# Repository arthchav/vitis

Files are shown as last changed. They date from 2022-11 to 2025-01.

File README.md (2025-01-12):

<p align="center">

  Vitis-Logo
</p>
Pour consulter les fonctionnalités et la réalisation du robot, veuillez consulter le document "Vitis - Rapport final de projet.pdf" dans les fichiers ci-dessus !

---------------------------------------------------

*"Vitis is a robot made for vineyards to help remove weeds under the vines. It runs on electricity, has four wheels, and can be controlled by a smartphone in manual or autonomous mode. It can move through different types of land, avoid small obstacles, and use a camera to recognize objects. The robot is easy to control and works well, but it will be improved to track vine rows better and add tools for removing weeds more effectively."*

# Last video : 

https://youtu.be/JAuiAB0MdsA

<p align="center">
  
</p>

### Playlist : 

https://youtube.com/playlist?list=PLRQ-Vj44Z8fejHV95dyqV7iqJ9uM6nV9p

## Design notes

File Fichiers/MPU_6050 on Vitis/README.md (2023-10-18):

# MPU-6050 on Vitis

<p align="center">

  Vitis-Logo
</p>

In our 4th year Robotics course, we had to use an inertial unit in a project. We naturally chose Vitis and the aim of the course is to display a cube representing Vitis moving in 3 dimensions. 

We used Arduino and Processing to display the cubes in 3D. 
There are 3 different codes, the first only with an accelerometer, the second only with a gyrometer and the last with both. 

<p align="center">

  Vitis-Logo
</p>

Finally, there's a bonus Arduino code for a remote control that controls the robot with the remote control's Roll and Pitch angles (Android smartphone only). 

<p align="center">

  Vitis-Logo
</p>

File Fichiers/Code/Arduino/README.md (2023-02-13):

## Code Arduino 

Dans section se trouve toutes les explications concernant les codes Arduino. pour l'instant il n'y a que 2 programmes qui seront combinés par la suite. 

Dans le futur ce dossier aura : 

- Un seul code qui combine le mode manuel et le mode automatique. 
- Des class, .h et .cpp qui rendent le code plus lisible et l'allège un peu.

<p align="center">
  
</p>

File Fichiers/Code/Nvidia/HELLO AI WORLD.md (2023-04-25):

# Running the Docker Container:

```
$ git clone --recursive https://github.com/dusty-nv/jetson-inference
$ cd jetson-inference
$ docker/run.sh
```
# Building the project from the Source:

### Cloning the Repository

```
$ sudo apt-get update
$ sudo apt-get install git cmake
```

```
$ git clone https://github.com/dusty-nv/jetson-inference
$ cd jetson-inference
$ git submodule update --init
```
### Python Packages

```
$ sudo apt-get install libpython3-dev python3-numpy
```

### Configuring with CMake

```
$ cd jetson-inference    # omit if working directory is already jetson-inference/ from above
$ mkdir build
$ cd build
$ cmake ../
```

### Installing PyTorch

```
$ cd jetson-inference/build
$ ./install-pytorch.sh
```

### Compiling the Project

```
$ cd jetson-inference/build          # omit if working directory is already build/ from above
$ make
$ sudo make install
$ sudo ldconfig
```

# Classifying Images with ImageNet

### Using the ImageNet Program on Jetson

```
$ cd jetson-inference/build/aarch64/bin
```

### Example

```
$ ./imagenet.py images/orange_0.jpg images/test/output_0.jpg  # (default network is googlenet)

$ ./imagenet.py images/strawberry_0.jpg images/test/output_1.jpg
```

Pour une vidéo:

```
$ wget https://nvidia.box.com/shared/static/tlswont1jnyu3ix2tbf7utaekpzcx4rc.mkv -O jellyfish.mkv

$ ./imagenet.py --network=resnet-18 jellyfish.mkv images/test/jellyfish_resnet18.mkv
```

# Coding Your Own Image Recognition Program (Python)

### Setting up the Project

```
# run these commands outside of container
$ cd ~/
$ mkdir my-recognition-python
$ cd my-recognition-python
$ touch my-recognition.py
$ chmod +x my-recognition.py
$ wget https://github.com/dusty-nv/jetson-inference/raw/master/data/images/black_bear.jpg 
$ wget https://github.com/dusty-nv/jetson-inference/raw/master/data/images/brown_bear.jpg
$ wget https://github.com/dusty-nv/jetson-inference/raw/master/data/images/polar_bear.jpg 
```
```
$ jetson-inference/docker/run.sh --volume ~/my-recognition-python:/my-recognition-python   # mounted inside the container to /my-recognition-python 
```

### Source Code

```
vim my-recognition.py
```
```
#!/usr/bin/python3

import jetson.inference
import jetson.utils

import argparse

# parse the command line
parser = argparse.ArgumentParser()
parser.add_argument("filename", type=str, help="filename of the image to process")
parser.add_argument("--network", type=str, default="googlenet", help="model to use, can be:  googlenet, resnet-18, ect.")
args = parser.parse_args()

# load an image (into shared CPU/GPU memory)
img = jetson.utils.loadImage(args.filename)

# load the recognition network
net = jetson.inference.imageNet(args.network)

# classify the image
class_idx, confidence = net.Classify(img)

# find the object description
class_desc = net.GetClassDesc(class_idx)

# print out the result
print("image is recognized as '{:s}' (class #{:d}) with {:f}% confidence".format(class_desc, class_idx, confidence * 100))
```

### Running Example

```
$ ./my-recognition.py polar_bear.jpg
image is recognized as 'ice bear, polar bear, Ursus Maritimus, Thalarctos maritimus' (class #296) with 99.999878% confidence
```

# Running the Live Camera Recognition Demo

Faire le Tuto 'Stream Vidéo'

```
imagenet --bitrate=1000000 --output-codec=h264 /dev/video0 rtp://172.20.10.2:9306
```

```
detectnet --bitrate=1000000 --output-codec=h264 /dev/video0 rtp://172.20.10.2:9306
```

Lancer la vidéo sur VLC et régalez-vous!

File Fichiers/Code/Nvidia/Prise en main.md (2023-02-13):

# Prise en main de la carte jetson nano:

<p align="center">
  
</p>

<p align="center">
  
</p>

Connexion à la carte jetson nano:
```shell
 ssh vitis@192.168.55.1
 ```

 # Déplacer le stockage de la mémoire nvidia vers la carte SD:

On check les partitions pour voir le nom de la carte avec la commande:

```shell
lsblk
```
La carte SD ce nomme "mmcblk1p1".

On veut maintenant la formater au format ext4 en tapant la commande:

```shell
sudo mkfs.ext4 /dev/mmcblk1p1
```
On crée ensuite un point de montage:

```shell
sudo mkdir -p /usr/Documents
```

Puis on monte la partition:

```shell
sudo mount -t auto /dev/mmclk1p1 /usr/Documents
```

On vérifie que la partition est bien montée avec:
```shell
lsblk -f
```

On copie /home vers le nouvel emplacement:

```shell
sudo rsync -avx /home/ /usr/Documents
```
On monte la nouvelle partition:
```shell
sudo mount /dev/mmcblk1p1
```

On récupère le UUID de la nouvelle partition et on modifie le fstab:

```shell
sudo blkid
sudo vim /etc/fstab
UUID=03d60d39-967e-473e-b710-2687941e1d0a /home ext4 defaults 0 2
```

Finalement on redémarre la carte et /home est désormais sur la carte SD
```shell
sudo shutdown -r now
```

# Utiliser les images docker fournies par Nvidia:

Installer le package nvidia-container, attention à bien être connecté en wifi avec la carte(voir annexe):
```shell
sudo apt install nvidia-container
```
On modifie le fichier /etc/docker/daemon.json en ajoutant:
```shell
"data-root":"/mnt/sd_card"
```

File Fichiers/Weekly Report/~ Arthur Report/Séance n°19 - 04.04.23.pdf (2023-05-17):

Arthur | Rapport de séance n°19 | Projet Vitis
| | 04/04/23

Objectifs de la séance :

- Fixer les drivers aux planches
- Fixer les planches au châssis
- Trouver une solution pour partager l’alimentation autre que des dominos.

Réalisations :

- Tout d’abord pré perçage et fixation des drivers aux planches avec vis et écrou de 3mm.

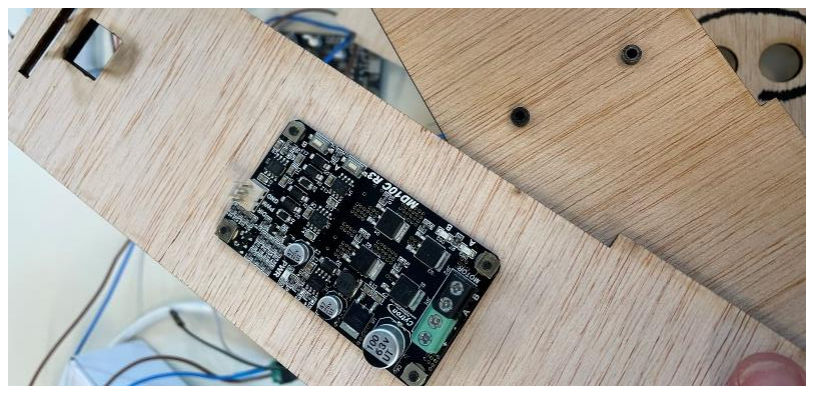
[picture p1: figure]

- On vient ensuite assembler les planches entre elles à l’aide d’équerres que je place en diagonale opposé par rapport au châssis car je n’ai que 2 équerres.

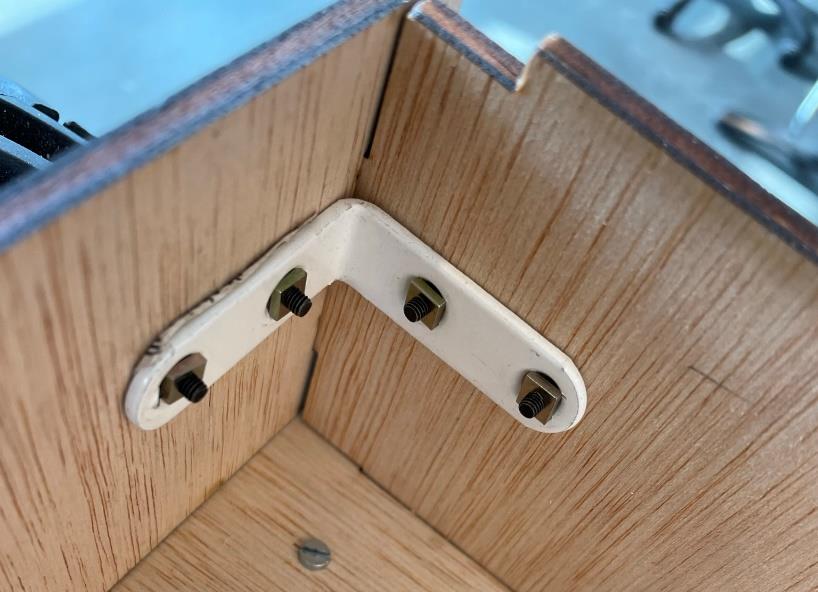
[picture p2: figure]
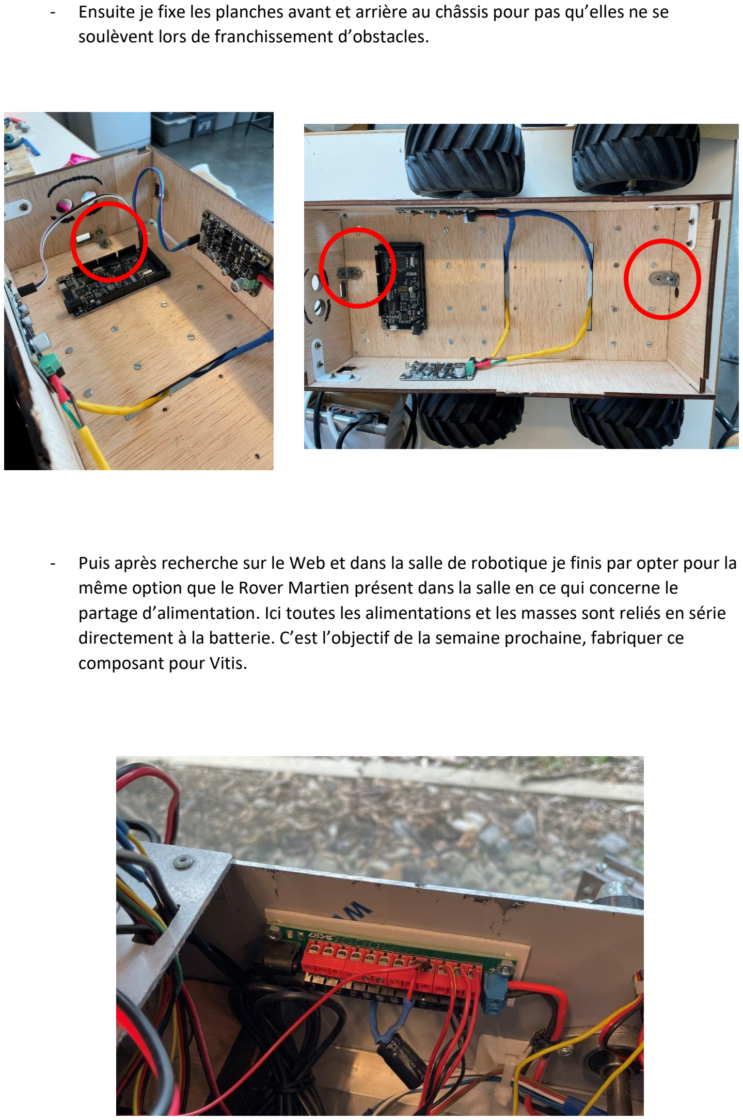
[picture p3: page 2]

- Ensuite je fixe les planches avant et arrière au châssis pour pas qu’elles ne se soulèvent lors de franchissement d’obstacles.
- Puis après recherche sur le Web et dans la salle de robotique je finis par opter pour la même option que le Rover Martien présent dans la salle en ce qui concerne le partage d’alimentation. Ici toutes les alimentations et les masses sont reliés en série directement à la batterie. C’est l’objectif de la semaine prochaine, fabriquer ce composant pour Vitis.

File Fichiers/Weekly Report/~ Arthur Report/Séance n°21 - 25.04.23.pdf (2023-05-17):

Arthur | Rapport de séance n°21 | Projet Vitis
| | 25/04/23

Objectifs de la séance :

- Fabriquer un composant pour partager la masse de la carte Arduino Mega.
- Changement du bois pour le plexiglas pour les 4 planches fixées au châssis.

Réalisations :

- Je commence par réaliser un composant où je peux connecter plus de10 masses ensemble puisque la carte Arduino ne possède pas assez de ports pour tout nos capteurs.

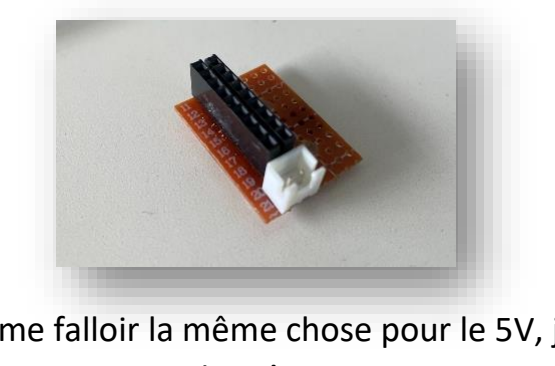
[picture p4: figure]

Après réflexion il va me falloir la même chose pour le 5V, je décide donc de recommencer pour avoir tout sur la même carte.

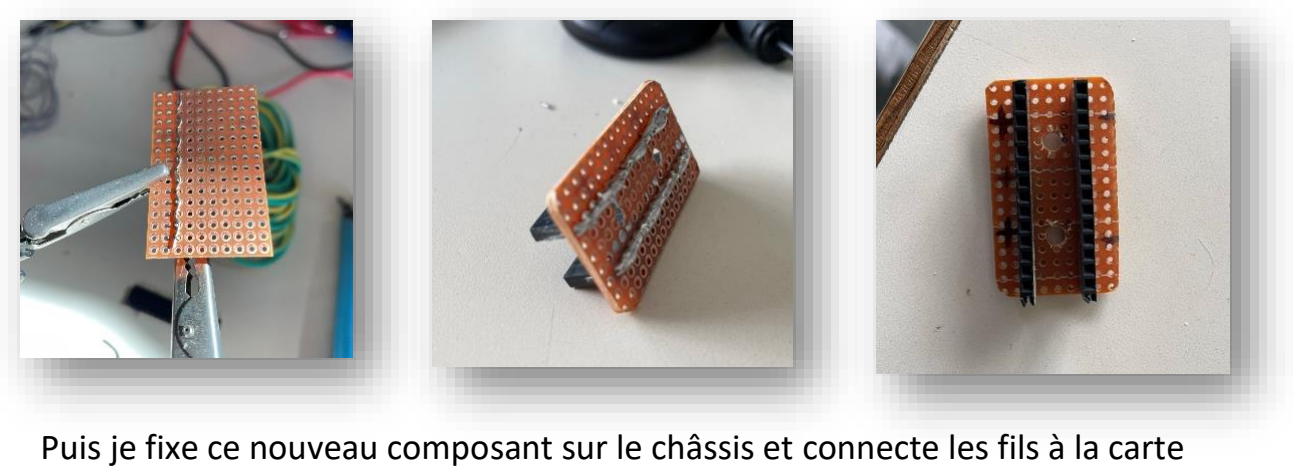
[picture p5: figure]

Puis je fixe ce nouveau composant sur le châssis et connecte les fils à la carte Arduino.

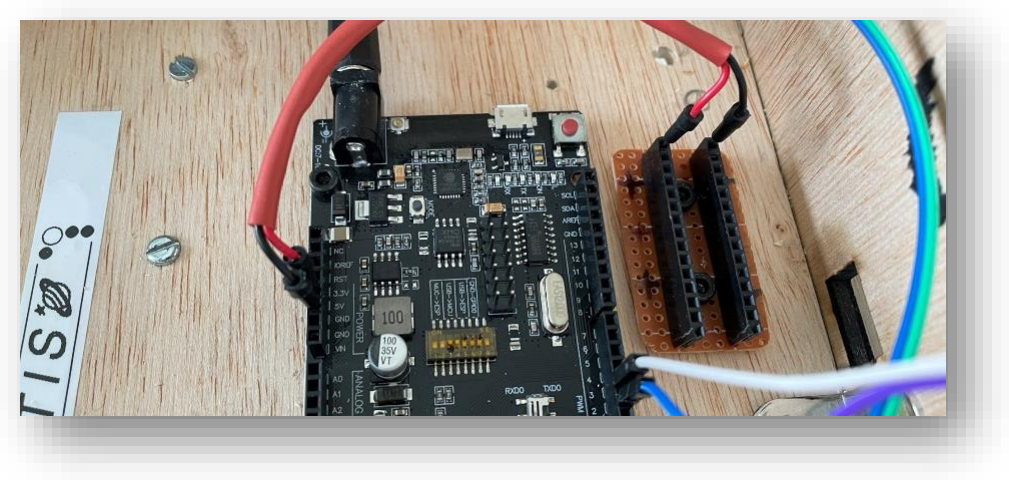
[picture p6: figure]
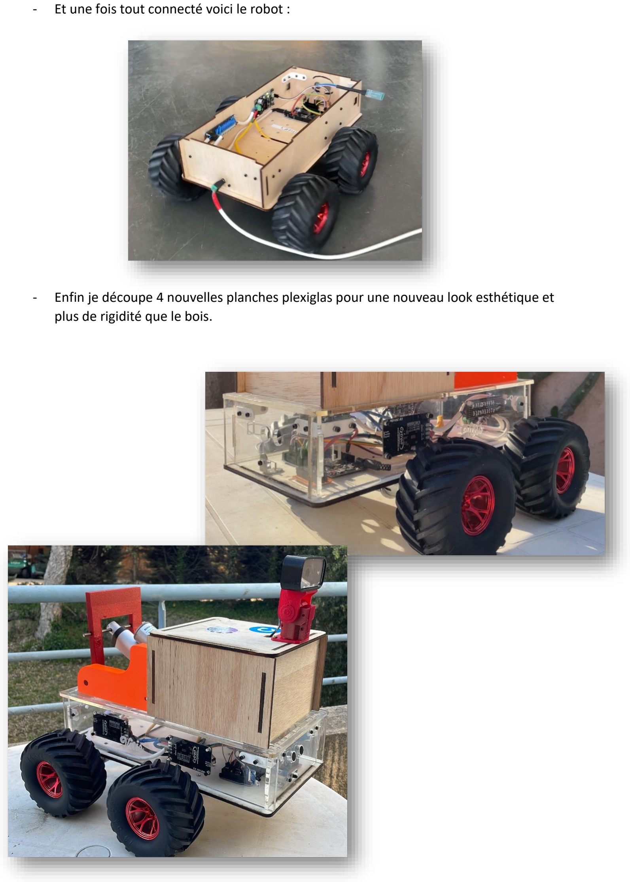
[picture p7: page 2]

- Et une fois tout connecté voici le robot :
- Enfin je découpe 4 nouvelles planches plexiglas pour une nouveau look esthétique et plus de rigidité que le bois.

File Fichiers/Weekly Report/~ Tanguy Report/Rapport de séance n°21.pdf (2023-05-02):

Rapport de Séance 02/05/23

Objectifs de séance:
-Carte Nvidia reconnaissance d’image -Programme Arduino servo-moteurs
I-Carte Nvidia Reconnaissance d’image

https://github.com/arthchav/vitis/tree/main/WorkSpace/Code%Vitis/Nvidia

II-Programme Arduino

Pour finir la partie sur la caméra, j’ai écris un code Arduino afin de permettre une rotation des servo-moteurs périodique. Cela permettra d’avoir une grande amplitude de capture d’image.

Code pour 1 servo-moteur:

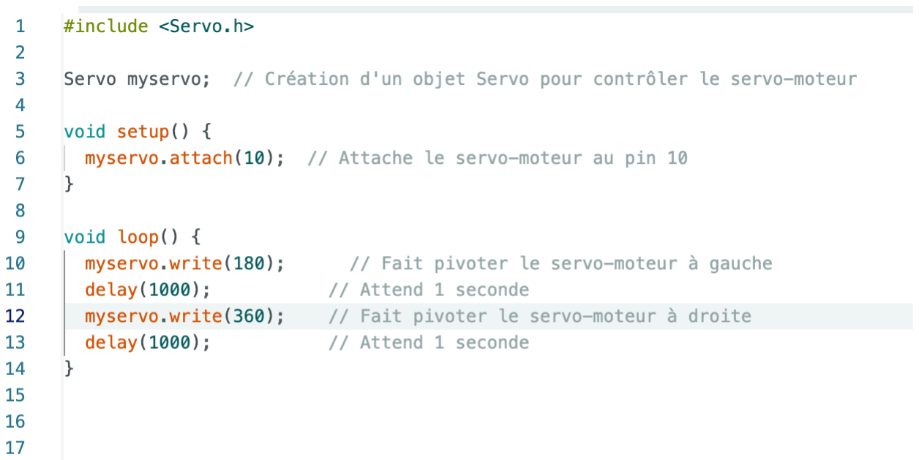
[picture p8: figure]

Code pour 2 servo-moteurs:

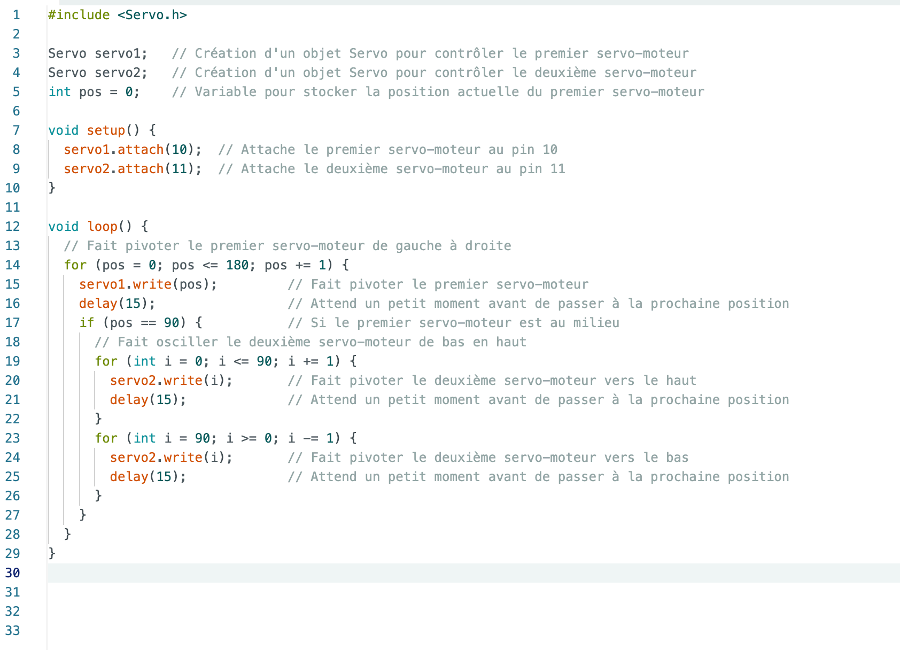
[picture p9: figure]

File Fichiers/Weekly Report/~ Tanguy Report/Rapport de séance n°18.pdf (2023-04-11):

Rapport de Séance 04/04/23

Objectifs de séance:
-Installation caméra
-Carte Nvidia reconnaissance d’image
I-Installation Caméra

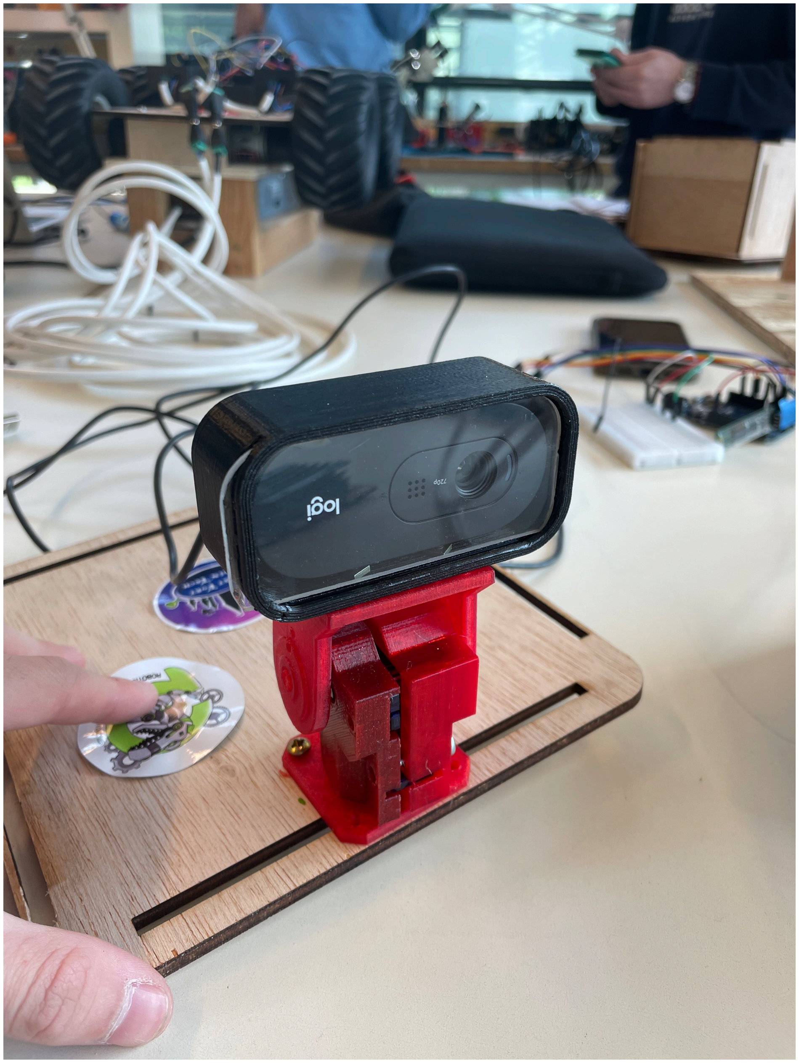
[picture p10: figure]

J’ai commencé par découper la vitre en plexi avec la découpeuse laser. Ensuite j’ai fixé à l’aide de vis la caméra au support tournant. Maintenant on a un bloc complet qui permet de bouger la caméra dans à peu près tout les sens qu’on veut. Ce support sera relié à la carte Arduino et la caméra sera relié à la carte Nvidia afin de pouvoir faire de la reconnaissance d’image.

II-Carte Nvidia Reconnaissance d’image

Voir tuto Workspace -> Nvidia

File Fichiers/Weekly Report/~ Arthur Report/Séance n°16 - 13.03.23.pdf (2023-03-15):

Arthur | Rapport de séance n°16 | Projet Vitis
| | 13/03/23

Objectifs de la séance :

- Changer le pad pour une télécommande à 4 directions
- Contrôler le bras (vérin) avec la télécommande

Réalisations :

- La première partie de la séance est destiné au contrôle du bras. Le bras est un vérin constitué d’un moteur à courant continu que l’on pilote en fonction du sens du courant.
Pour le contrôler à l’aide du smartphone, on utilise un interrupteur virtuel en vert sur le schéma :

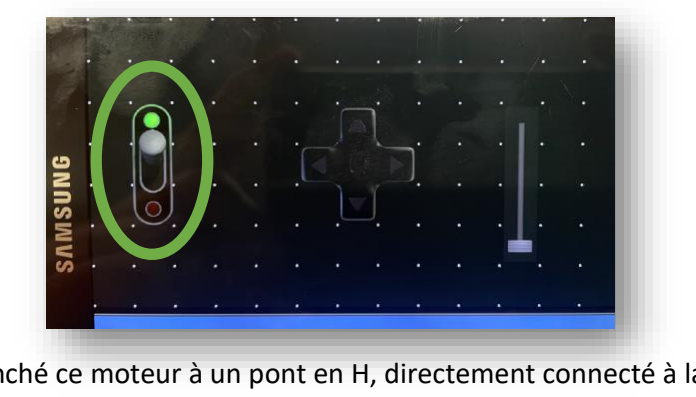
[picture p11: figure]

Puis j’ai branché ce moteur à un pont en H, directement connecté à la carte Arduino.

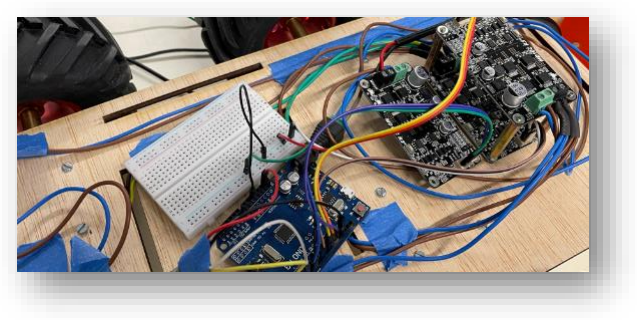
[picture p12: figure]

- Ensuite pour diriger le robot, j’ai épuré l’ancien code qui contrôlait le robot avec une télécommande 4 directions. Aussi dans ce code le robot change sa façon de tourner, désormais le robot tourne sur lui-même pour s’orienter en faisant tourner les roues opposées dans des sens contraires.

Or pour palier au problème des moteurs qui passent de 0 à 100% de leurs capacités, j’ai ajouté un slider à la télécommande qui contrôle la vitesse en direct :

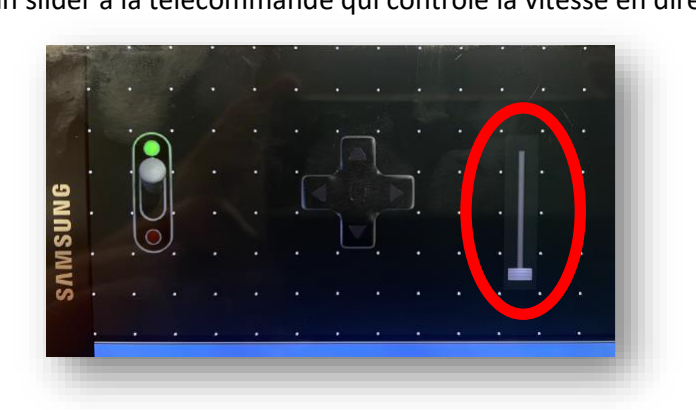
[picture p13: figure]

Nous avons désormais un robot qui se contrôle entièrement avec le smartphone, bras compris.

15/03/2023 14:10 | telecommande_et_bras.ino
localhost:65218/e22d77b5-10ca-4890-aacf-ff817043206c/ | 1/2

## telecommande_et_bras.ino

#include <SoftwareSerial.h>

SoftwareSerial BT(4, 2); // RX, TX

#define dir_g 8

#define pwm_g 6

#define dir_d 10

#define pwm_d 11

#define dir_b 12

#define pwm_b 5

int speed = 0;

void setup() {
pinMode(dir_g, OUTPUT);
pinMode(pwm_g, OUTPUT);
pinMode(dir_d, OUTPUT);
pinMode(pwm_d, OUTPUT);
pinMode(dir_b, OUTPUT);
pinMode(pwm_b, OUTPUT);

// Configuration de la liaison Bluetooth BT.begin(9600);

// Initialise les pins à l'état bas digitalWrite(dir_g, LOW);
analogWrite(pwm_g, 0);
digitalWrite(dir_d, LOW);
analogWrite(pwm_d, 0);
digitalWrite(dir_b, LOW);
analogWrite(pwm_b, 0);
}

void loop() {
if (BT.available()) {
char c = BT.read();

// Si la commande est une commande de direction if (c == 'U') {
digitalWrite(dir_g, HIGH); digitalWrite(dir_d, HIGH); analogWrite(pwm_g, speed); analogWrite(pwm_d, speed);

} else if (c == 'D') {
digitalWrite(dir_g, LOW);
digitalWrite(dir_d, LOW);
analogWrite(pwm_g, speed); analogWrite(pwm_d, speed);

} else if (c == 'L') {
digitalWrite(dir_g, LOW);
digitalWrite(dir_d, HIGH); analogWrite(pwm_g, speed);

15/03/2023 14:10 | telecommande_et_bras.ino
localhost:65218/e22d77b5-10ca-4890-aacf-ff817043206c/ | 2/2

analogWrite(pwm_d, speed);

} else if (c == 'R') {
digitalWrite(dir_g, HIGH); digitalWrite(dir_d, LOW);
analogWrite(pwm_g, speed); analogWrite(pwm_d, speed);
}
// Si la commande est une commande de vitesse else if (c == 'V') {
speed = BT.parseInt();
analogWrite(pwm_g, speed); analogWrite(pwm_d, speed);

}

else if (c == 'B') {
digitalWrite(dir_b, LOW);
analogWrite(pwm_b, 255);
}
else if (c == 'H') {
digitalWrite(dir_b, HIGH); analogWrite(pwm_b, 255);
}

}
}

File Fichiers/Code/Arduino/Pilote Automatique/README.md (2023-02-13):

## Explication du code pilote automatique

Ce programme est fait pour un robot équipé de 4 moteurs, d'un capteur de distance à ultrasons et de deux capteurs infrarouges. Il utilise une carte Arduino pour contrôler les moteurs et lire les données des capteurs.
Le robot avance constamment sauf si il y a un obstacle devant ou sur les côtés.

Les variables déclarées en haut du code incluent "duree" pour stocker la durée de l'écho du signal ultrasonique, "distance" pour stocker la distance mesurée, "V_avant" pour stocker la valeur à partir de laquelle le robot avance, et "V_arriere" pour stocker la valeur à partir de laquelle le robot recule.

```shell
// Variables utiles dans la suite du code

long duree;   // durée de l'echo ultrason   
int distance; // variable qui stock la distance ultrason 

int V_avant=20; // Valeur à partir de laquelle le robot avance 
int V_arriere=19; //Valeur à partir de laquelle le robot recul 

```

Ensuite, les broches de l'Arduino sont nommées pour une meilleure lisibilité du code. Les broches du module L298N sont associées à des broches de l'Arduino, ainsi que les broches du capteur ultrason et des capteurs infrarouges.

```shell

// On commence par nommé chaque borne pour un code lisible :

#define borneENA 10 // On associe la borne "ENA" du L298N à la pin D10 de l'arduino
#define borneENB 5  // On associe la borne "ENB" du L298N à la pin D5 de l'arduino

#define PinDROITE_avant 7  // fait avancer le côté droit (borne IN3 du pont en H)
#define PinDROITE_recule 6 // fait reculer le côté droit (borne IN4 du pont en H)
#define PinGAUCHE_avant 9  // fait avancer le côté gauche (borne IN1 du pont en H)
#define PinGAUCHE_recule 8 // fait reculer le côté gauche (borne IN2 du pont en H)

#define echoPin        12       // Echo    (réception ultrason)
#define trigPin        11       // Trigger (emission ultrason)

#define PinCapteurIR1   52       // OUT du capteur IR 1 (Gauche)
#define PinCapteurIR2   53       // OUT du capteur IR 2 (Droite)
```

Dans la fonction setup(), les broches sont configurées en mode "entrée" ou "sortie" en fonction de leur utilisation. On note la présence d'un potentiomètre qui gère la vitesse des moteurs dans le robot. 

```shell
void setup() {

pinMode(trigPin, OUTPUT); // Configuration du port du Trigger comme une SORTIE
pinMode(echoPin, INPUT);  // Configuration du port de l'Echo  comme une ENTREE

// Configuration de toutes les pins de l'Arduino en "sortie" (car elles attaquent les entrées du module L298N)
  pinMode(borneENA, OUTPUT);
  pinMode (PinGAUCHE_avant , OUTPUT);
  pinMode (PinGAUCHE_recule, OUTPUT);
  pinMode (PinDROITE_avant , OUTPUT);
  pinMode (PinDROITE_recule, OUTPUT);
  pinMode(borneENB, OUTPUT);

  pinMode(A1, INPUT); // Pour la vitesse avec le potentiometre 

  Serial.begin(9600); // Démarrage de la communication série

// IR :
  pinMode (PinCapteurIR1, INPUT);
  pinMode (PinCapteurIR2, INPUT);

}
```
Dans la fonction loop(), un signal ultrason est émis et la distance des obstacles est calculée en utilisant la durée de l'echo. Les données des capteurs infrarouges sont également lues pour détecter les obstacles à gauche et à droite. En fonction de ces données, le robot peut tourner à gauche ou à droite pour éviter les obstacles. Sinon, il avance constamment.

```shell
void loop() {

  // Émission d'un signal de durée 10 microsecondes
  digitalWrite(trigPin, LOW);
  delayMicroseconds(5);
  digitalWrite(trigPin, HIGH);
  delayMicroseconds(10);
  digitalWrite(trigPin, LOW);

  // Écoute de l'écho 
  duree = pulseIn(echoPin, HIGH);

  // Calcul de la distance
  distance = duree*0.034/2;

// Reception des données des capteurs IR : 

int CapteurIR1 = digitalRead(PinCapteurIR1);
int CapteurIR2 = digitalRead(PinCapteurIR2);

// On regarde si il y a un obstacle à Gauche puis à Droite 

if (CapteurIR1 == 0) { // Obstacle à gauche donc tourne à droite
  droite();
  return;
}
if (CapteurIR2 == 0) { // Obstacle à droite donc tourne à gauche  
  gauche();
  return;
}

// Le robot avance constament sauf si il y a un obstacle devant

if (distance > V_avant){
  avant(); // On configurer les pins en mode "avant"
  lancerRotationMoteurPont(); // Puis on lance les moteurs ) la vitesse du potentiomètre 
}  
 else if (distance < V_arriere){
    arriere(); // On configurer les pins en mode "arrière"
    lancerRotationMoteurPont(); // Puis on lance les moteurs ) la vitesse du potentiomètre 
  }   
  
  else {
      stop_moteur(); // Lorque l'on est entre les distances de marche avant et arrière pour que le robot s'arrête devant l'obstacle 
}

}
```
Il y a des fonctions définies pour les actions de base.

```shell

void avant() {
    // Configuration du L298N en "marche avant", pour le moteur connecté au pont B. Selon sa table de vérité, il faut que :
  digitalWrite(borneIN3, HIGH);                 // L'entrée IN3 doit être au niveau haut
  digitalWrite(borneIN4, LOW);                  // L'entrée IN4 doit être au niveau bas
  
   //Configuration du L298N en "marche avant", pour le moteur connecté au pont A. Selon sa table de vérité, il faut que :
  digitalWrite(borneIN1, HIGH);                 // L'entrée IN1 doit être au niveau haut
  digitalWrite(borneIN2, LOW);                  // L'entrée IN2 doit être au niveau bas

}

void arriere() {
  // Puis on configure le L298N en "marche arrière", pour le moteur câblé sur le pont B. Selon sa table de vérité, il faut que :
  digitalWrite(borneIN3, LOW);                  // L'entrée IN3 doit être au niveau bas
  digitalWrite(borneIN4, HIGH);                 // L'entrée IN4 doit être au niveau haut

  // Puis on configure le L298N en "marche arrière", pour le moteur câblé sur le pont A. Selon sa table de vérité, il faut que :
  digitalWrite(borneIN1, LOW);                  // L'entrée IN1 doit être au niveau bas
  digitalWrite(borneIN2, HIGH);                 // L'entrée IN2 doit être au niveau haut

}

void gauche()
{

    digitalWrite(PinGAUCHE_avant, LOW);
    digitalWrite(PinGAUCHE_recule, HIGH);
    digitalWrite(PinDROITE_avant, HIGH);
    digitalWrite(PinDROITE_recule, LOW);
}

void droite()
{

    digitalWrite(PinGAUCHE_avant, HIGH);
    digitalWrite(PinGAUCHE_recule, LOW);
    digitalWrite(PinDROITE_avant, LOW);
    digitalWrite(PinDROITE_recule, HIGH);
}

void stop_moteur() {

  analogWrite(borneENB, 0); //Stop les moteurs 
  analogWrite(borneENA, 0);       

}

```
Enfin une fonction qui permet de lire la vitesse à laquelle les moteurs doivent tourner à chaque tour de boucle (void loo()).
```shell
void lancerRotationMoteurPont() {

    int vitesse = analogRead(A1);  // lit la valeur du potentiomètre

    vitesse = map(vitesse, 0, 1023, 0, 255); // Convertie linéairement la valeur entre 0 et 255

    analogWrite(borneENB, vitesse); // Lance les moteurs 
    analogWrite(borneENA, vitesse);     

}
```

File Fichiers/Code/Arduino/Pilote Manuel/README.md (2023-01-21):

## Explication du code pilote manuel 

Ce code permet de contrôler un robot à l'aide d'une carte Arduino Mega et d'un téléphone connecté en Bluetooth. Il utilise un pont en H (L298N) pour contrôler les moteurs côté gauche et côté droit du robot.

Au début du code, des constantes sont définies pour nommé les différentes broches de l'Arduino qui sont utilisées pour contrôler le pont en H. La broche ENA du L298N est connectée à la pin D10 de l'Arduino et la broche ENB est connectée à la pin D5. Les broches IN1 et IN2 du pont en H sont connectées aux broches D9 et D8 pour contrôler les moteurs gauches et les broches IN3 et IN4 sont connectées aux broches D7 et D6 pour contrôler les moteurs droits.

```shell
#define borneENA 10 // On associe la borne "ENA" du L298N à la pin D10 de l'arduino
#define borneENB 5  // On associe la borne "ENB" du L298N à la pin D5 de l'arduino

#define PinDROITE_avant 7  // fait avancer le côté droit (borne IN3 du pont en H)
#define PinDROITE_recule 6 // fait reculer le côté droit (borne IN4 du pont en H)
#define PinGAUCHE_avant 9  // fait avancer le côté gauche (borne IN1 du pont en H)
#define PinGAUCHE_recule 8 // fait reculer le côté gauche (borne IN2 du pont en H)
```

Dans la fonction "setup()", les pins de l'Arduino sont configurées en sortie car elles attaquent les entrées du module L298N. La communication série est également démarrée pour permettre la communication avec le téléphone via Bluetooth.

```shell
void setup()
{

    // Configuration de toutes les pins de l'Arduino en "sortie" (car elles attaquent les entrées du module L298N)
    pinMode(borneENA, OUTPUT);
    pinMode(borneENB, OUTPUT);

    pinMode(PinGAUCHE_avant, OUTPUT);
    pinMode(PinGAUCHE_recule, OUTPUT);
    pinMode(PinDROITE_avant, OUTPUT);
    pinMode(PinDROITE_recule, OUTPUT);

    Serial.begin(9600); // Démarrage de la communication série
    Serial1.begin(9600); // Démarrage de la communication du cerveau 1 de l'aruduino Mega

}
```

Dans la boucle "loop()", une variable "etat" est utilisée pour récupérer les dernières communications Bluetooth. En fonction de la valeur de "etat", différentes fonctions sont appelées pour contrôler le mouvement du robot : "avant()", "arriere()", "gauche()", "droite()" ou "stop_moteur()".

```shell
char etat; // Nouvelle variable qui contient les dernières communication Bluetooth 

void loop()

{

etat=(Serial1.read()); // On récupère l'information Bluetooth 

  if (etat=='H')
  {
    avant();
    }

  else if (etat=='B')
  {
    arriere();
    }

  else if (etat=='G')
  {
    gauche();
    }

  else if (etat=='D')
  {
    droite(); 
    }

  else if (etat=='S')
  {
    stop_moteur();
    }

}

```

La fonction "avant()" configure le pont en H en "marche avant" pour les quatres moteurs, en utilisant les broches IN1, IN2, IN3 et IN4. La fonction "arriere()" configure le pont en H en "marche arrière" pour les quatres moteurs. Les fonctions "gauche()" et "droite()" permettent de tourner le robot dans ces directions. Et enfin, la fonction "stop_moteur()" stoppe les moteurs.

```shell
void avant()
{

    // Le fait d'utiliser analogWrite fait que l'on peut utiliser une puissance personalisé, ici on utilise 200/256 de puissance.     
    analogWrite(borneENB, 200);
    analogWrite(borneENA, 200);

    // Configuration du L298N en "marche avant", pour le moteur connecté au pont B. Selon sa table de vérité, il faut que :
    digitalWrite(borneIN3, HIGH); // L'entrée IN3 doit être au niveau haut
    digitalWrite(borneIN4, LOW);  // L'entrée IN4 doit être au niveau bas

    // Configuration du L298N en "marche avant", pour le moteur connecté au pont A. Selon sa table de vérité, il faut que :
    digitalWrite(borneIN1, HIGH); // L'entrée IN1 doit être au niveau haut
    digitalWrite(borneIN2, LOW);  // L'entrée IN2 doit être au niveau bas
}

void arriere()
{
    // Le fait d'utiliser analogWrite fait que l'on peut utiliser une puissance personalisé, ici on utilise 200/256 de puissance. 
    analogWrite(borneENB, 200);
    analogWrite(borneENA, 200);

    // Puis on configure le L298N en "marche arrière", pour le moteur câblé sur le pont B. Selon sa table de vérité, il faut que :
    digitalWrite(borneIN3, LOW);  // L'entrée IN3 doit être au niveau bas
    digitalWrite(borneIN4, HIGH); // L'entrée IN4 doit être au niveau haut

    // Puis on configure le L298N en "marche arrière", pour le moteur câblé sur le pont A. Selon sa table de vérité, il faut que :
    digitalWrite(borneIN1, LOW);  // L'entrée IN1 doit être au niveau bas
    digitalWrite(borneIN2, HIGH); // L'entrée IN2 doit être au niveau haut
}

void gauche()
{
    // Le fait d'utiliser analogWrite fait que l'on peut utiliser une puissance personalisé, ici on utilise 200/256 de puissance. 
    analogWrite(borneENB, 200);
    analogWrite(borneENA, 200);

    digitalWrite(PinGAUCHE_avant, LOW);
    digitalWrite(PinGAUCHE_recule, HIGH);
    digitalWrite(PinDROITE_avant, HIGH);
    digitalWrite(PinDROITE_recule, LOW);
}

void droite()
{
    // Le fait d'utiliser analogWrite fait que l'on peut utiliser une puissance personalisé, ici on utilise 200/256 de puissance. 
    analogWrite(borneENB, 200);
    analogWrite(borneENA, 200);

    digitalWrite(PinGAUCHE_avant, HIGH);
    digitalWrite(PinGAUCHE_recule, LOW);
    digitalWrite(PinDROITE_avant, LOW);
    digitalWrite(PinDROITE_recule, HIGH);
}

void stop_moteur()
{

    // Le fait d'utiliser analogWrite fait que l'on peut utiliser une puissance personalisé, mais ici un DigitalWrite aurait fonctionner puisque l'on applique 0.
    analogWrite(borneENB, 0);
    analogWrite(borneENA, 0);
}

```

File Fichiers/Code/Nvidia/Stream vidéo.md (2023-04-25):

# Stream la vidéo de la caméra sur l'ordinateur(MacOs)

Problème rencontré:
-impossibilité d'ouvrir une fenêtre vidéo sur le terminal de la carte.

Solution proposé:
-Envoyé le flux vidéo de la caméra connecté à la carte vers un ordinateur connecté au même réseau internet.

## Enregistrer une vidéo de la caméra et l'enregistrer sur mon ordinateur:

```
video-viewer /dev/video0 test-webcam.mp4
```

Sur le terminal de l'ordinateur:

```
scp vitis@192.168.55.1:/home/vitis/test-webcam.mp4 Documents
```

Puis vérifier dans le finder que le fichier est bien présent et qu'on a bien une vidéo de la caméra.

## Stream le flux vidéo de la caméra avec VLC

Connecter la carte et l'ordinateur au même réseau. 
Ici, l'adresse IP du wifi est 172.20.10.2. (voir tuto de Prise en Main)

Création du fichier sdp:

```
vim stream_jetson.sdp
```

Contenue du fichier:

```
c=IN IP4 127.0.0.1
m=video 9306 RTP/AVP 96
a=rtpmap:96 H264/90000
```

Lancer la diffusion vidéo de la caméra:

```
video-viewer --bitrate=1000000 --output-codec=h264 /dev/video0 rtp://172.20.10.2:9306
```

Lancer la vidéo sur son ordinateur avec VLC:

```
/Applications/VLC.app/Contents/MacOS/VLC stream_jetson.sdp

```

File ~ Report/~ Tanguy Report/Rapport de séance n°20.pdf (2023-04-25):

Rapport de Séance 25/04/23

Objectifs de séance:
-Carte Nvidia reconnaissance d’image
I-Carte Nvidia Reconnaissance d’image

https://github.com/arthchav/vitis/tree/main/WorkSpace/Code%Vitis/Nvidia

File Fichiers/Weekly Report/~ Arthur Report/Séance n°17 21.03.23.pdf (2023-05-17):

Arthur | Rapport de séance n°17 | Projet Vitis
| | 21/03/23

Objectifs de la séance :

- Filmer une vidéo pour diffuser sur les réseaux de Polytech Nice Sophia

Réalisations :

- Nous avons d’abord créé un faux rang de vigne en fixant planches à la verticale. Puis nous avons fabriquer un outil pour le porte outil à l’aide de fil de fer. Enfin nous avons placer des herbes et bois au centre pour simuler un ramassage.
- Les vidéos ont été tournées par M. Masson pendant que nous faisions la démonstration.

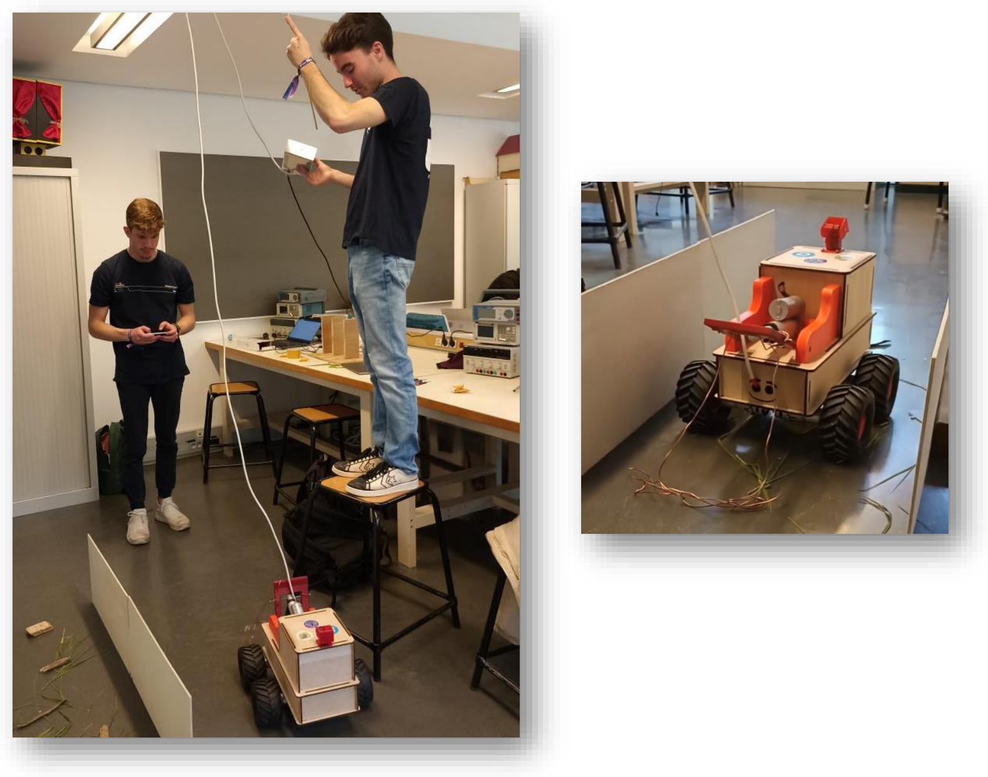
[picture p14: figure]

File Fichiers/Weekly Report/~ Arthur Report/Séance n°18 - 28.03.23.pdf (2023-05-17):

Arthur | Rapport de séance n°18 | Projet Vitis
| | 28/03/23

Objectifs de la séance :

- Ajouter des gaines thermo de partout de manière à sécuriser électriquement le robot.
- Faire les trous nécessaires à l’avant et sur les côtés du robot pour les capteurs.

Réalisations :

- J’ai commencé par déconnecter les cartes existantes et mettre de côté l’électronique sans tout débranché pour ne pas avoir à tout refaire après.

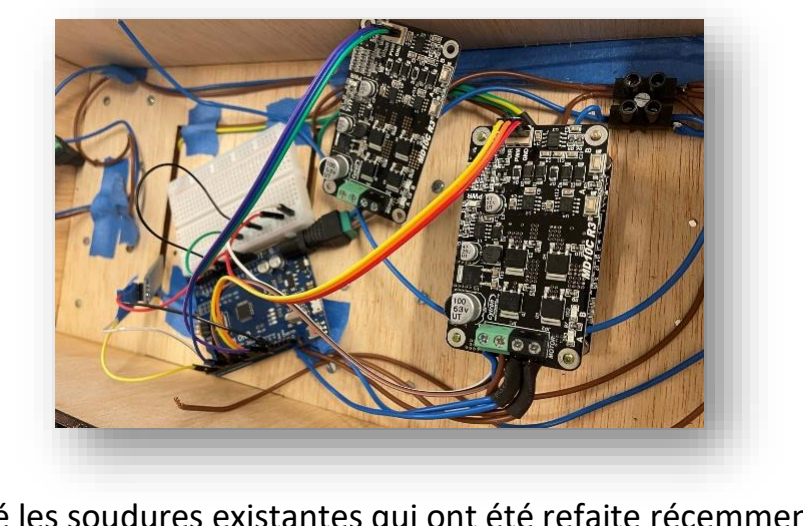
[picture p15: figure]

Puis j’ai utilisé les soudures existantes qui ont été refaite récemment pour ajouter les gaines thermo définitives. Certaines soudures ont dû être changer car trop épaisses pour la gaine. Enfin j’ai revissé la carte au châssis.

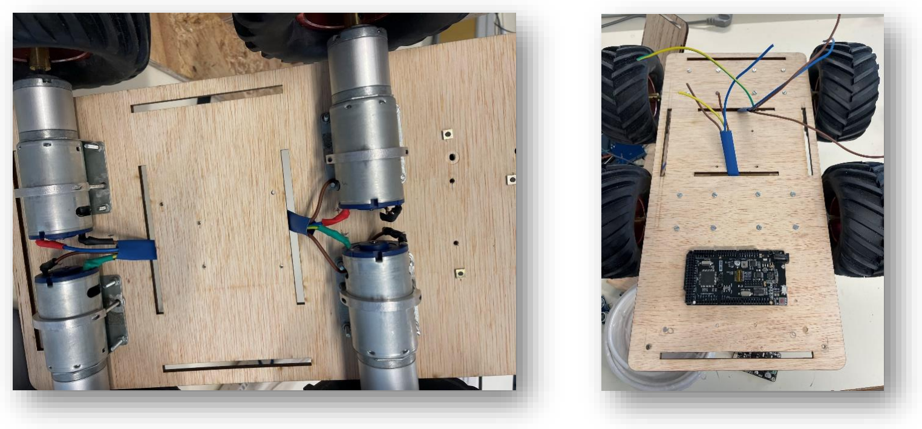
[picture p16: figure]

- Dans un second temps j’ai pris les mesures de taille des capteurs et de l’alimentation pour faires les trous nécessaires dans les 4 planches des côtés.

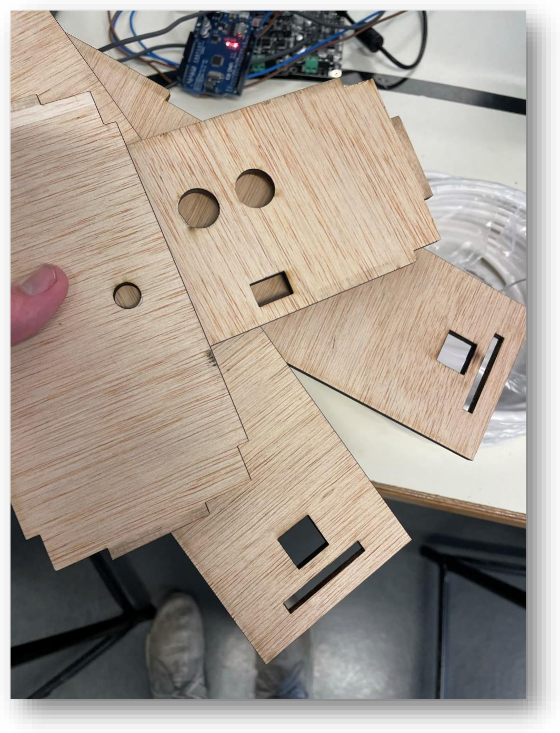
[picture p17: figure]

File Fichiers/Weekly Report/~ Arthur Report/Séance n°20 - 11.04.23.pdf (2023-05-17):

Arthur | Rapport de séance n°20 | Projet Vitis
| | 11/04/23

Objectifs de la séance :

- Fabrication du composant qui permet de multiplier les alimentations.
- Test du composant
- Installation du composant
- Fabrication des équerres manquantes lors de la dernière séance.

Réalisations :

- Après avoir étudier celui du Rover Martien j’ai commencé la fabrication de celui pour Vitis. Il c’est simple il faut se munir d’une carte électronique vierge et y placer le nombre de ports souhaité. Ensuite on retourne la carte puis on soude chaque patte « + » ensemble et chaque patte « – » également. Ce qui devrait donner ceci :

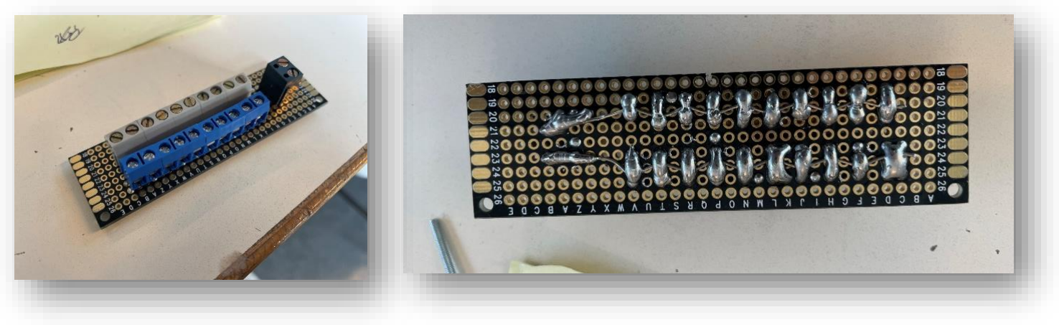
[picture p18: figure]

Ensuite place au test, on branche du 12V sur la borne noire et on test chacun des ports pour pas qu’il y est de ports non alimentés ou de court-circuit. Ici le test est réussi, tous les ports sont fonctionnels.

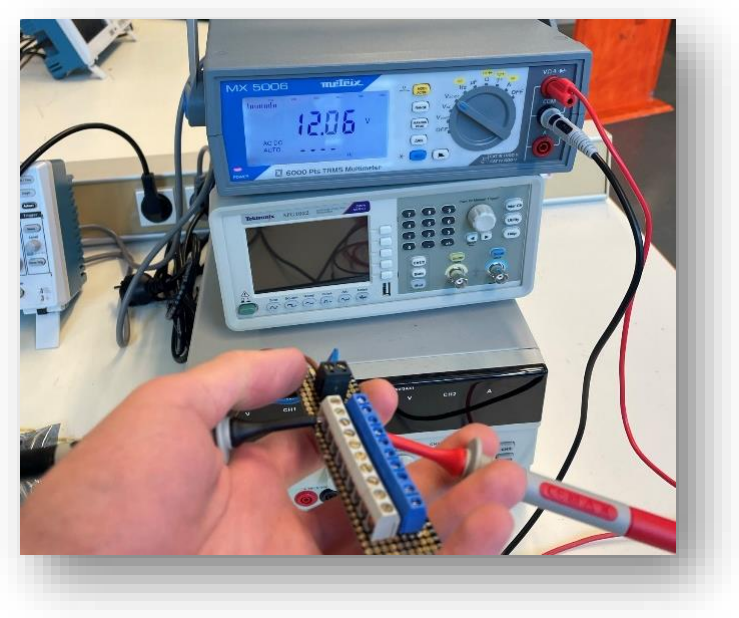
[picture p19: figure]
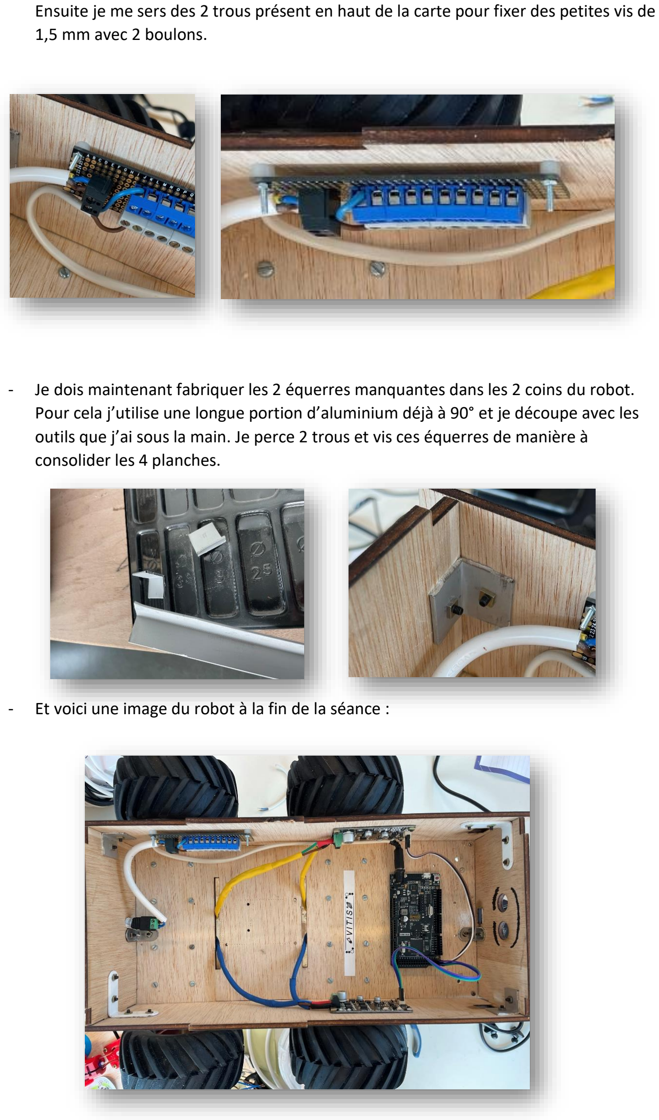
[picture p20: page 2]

Ensuite je me sers des 2 trous présent en haut de la carte pour fixer des petites vis de 1,5 mm avec 2 boulons.

- Je dois maintenant fabriquer les 2 équerres manquantes dans les 2 coins du robot. Pour cela j’utilise une longue portion d’aluminium déjà à 90° et je découpe avec les outils que j’ai sous la main. Je perce 2 trous et vis ces équerres de manière à consolider les 4 planches.
- Et voici une image du robot à la fin de la séance :

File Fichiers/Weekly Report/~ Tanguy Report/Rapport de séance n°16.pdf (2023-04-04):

Rapport de Séance 21/03/23

Objectifs de séance:
-Vidéos
Faire la vidéos de Vitis en fonctionnement

Cette séance a permit de faire une vidéo de Vitis en fonctionnement, pour cela on a installer des planches représentant les vignes et on a simuler un passage dans un rang de vigne.

La vidéo est à voir sur la chaîne YouTube.

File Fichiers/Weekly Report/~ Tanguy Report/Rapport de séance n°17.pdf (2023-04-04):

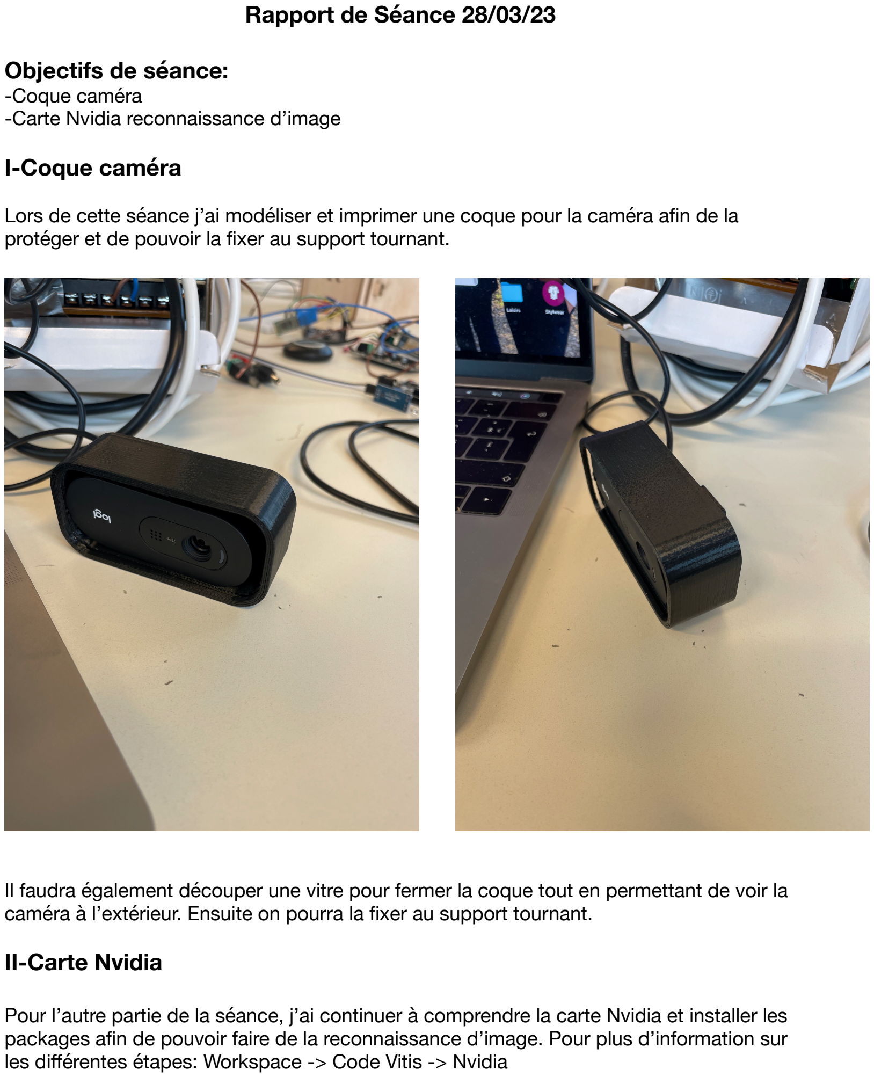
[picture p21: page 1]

Rapport de Séance 28/03/23

Objectifs de séance:
-Coque caméra
-Carte Nvidia reconnaissance d’image
I-Coque caméra

Lors de cette séance j’ai modéliser et imprimer une coque pour la caméra afin de la protéger et de pouvoir la fixer au support tournant.

Il faudra également découper une vitre pour fermer la coque tout en permettant de voir la caméra à l’extérieur. Ensuite on pourra la fixer au support tournant.
II-Carte Nvidia

Pour l’autre partie de la séance, j’ai continuer à comprendre la carte Nvidia et installer les packages afin de pouvoir faire de la reconnaissance d’image. Pour plus d’information sur les différentes étapes: Workspace -> Code Vitis -> Nvidia

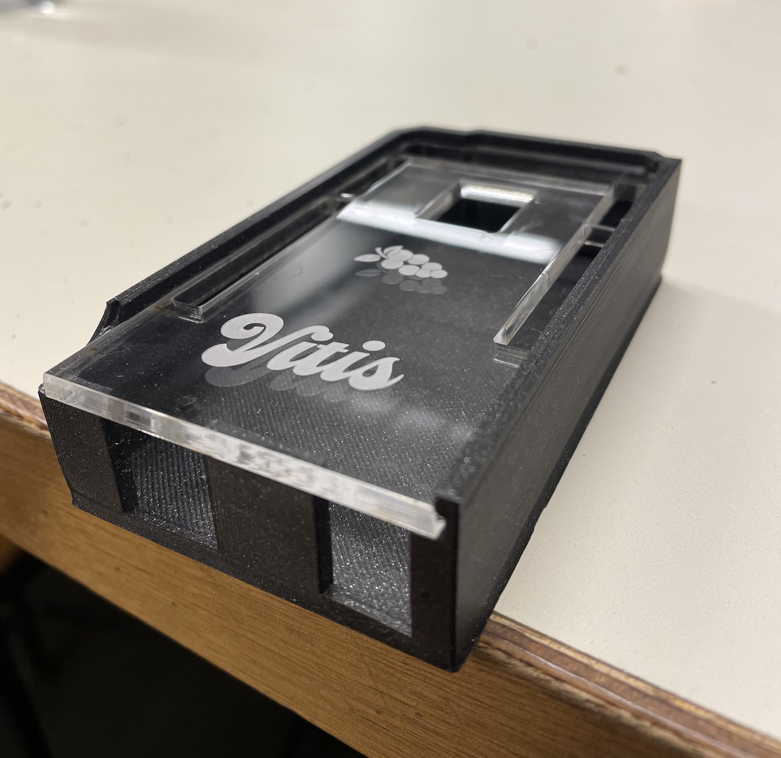
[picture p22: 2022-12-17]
Fichiers/~ Polytech/Arthur Work/Projet Boîte Arduino Mega - Fusion 360/Photo Boîte.jpg

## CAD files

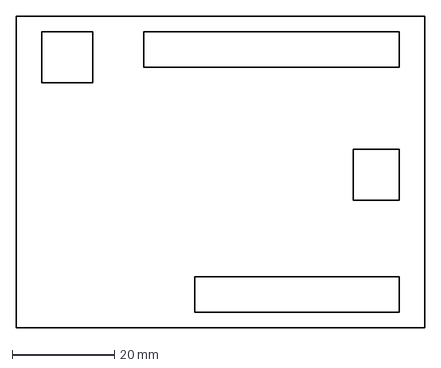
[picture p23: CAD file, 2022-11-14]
Fichiers/~ Polytech/Tanguy Work/Boîte Arduino CAO/vitre.dxf
80.0 x 61.0 mm

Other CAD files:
Fichiers/~ Polytech/Arthur Work/Projet Boîte Arduino Mega - Fusion 360/Boîte Arduino Mega Export .f3d
Fichiers/~ Polytech/Tanguy Work/Boîte Arduino CAO/Boite Finale v3.f3d

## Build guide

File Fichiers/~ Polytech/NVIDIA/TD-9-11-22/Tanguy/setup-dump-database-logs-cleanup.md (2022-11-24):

# Comment configurer le controle des logs:

Pour envoyer les logs on rajoute la commande ci dessous dans le script:
```shell
echo "Backup finished" >> /var/log/dump-mysql.log
```
La commande ulimit permet de contrôller le volume des logs:
```shell

ulimit -f$((10*1024))
```

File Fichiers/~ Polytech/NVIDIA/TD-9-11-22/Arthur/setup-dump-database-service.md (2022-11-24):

Le service est l'outil qui va nous permettre de lancer notre script de sauvegarde : 

 ```shell 
 [Service]
ExecStart=/home/arthur/dump-database.sh
```
On désactive la sauvegarde si aucun utilisateur n'est connecté : 
 ```shell 
[Install]
WantedBy=multi-user.target
```

Puis on lance ce servir toutes les 10 mins, pour cela on nomme un ``.timer`` avec le même nom que notre service : 

```shell
[Timer]
OnUnitActiveSec=10min
```

Le problème est que le service requiert des droits pour manipuler la base de donnée que l'utilisateur n'a pas. Nous allons donc donner les droits à l'utilisateur pour que le service puisse se lancer. 

On commence par reconfigurer MySQL pour ajouter un mot de passe fort d'accès : 

```shell 
sudo mysql_secure_installation
```

Une fois avoir suivi les instructions à l'écran, nous pouvons créer notre super utilisateur qui pourra lancer le service : 
```shell
mysql> CREATE USER 'arthur'@'localhost' IDENTIFIED BY 'Superazerty123?';
```
Puis lui donner les droits : 
```shell 
mysql> GRANT PROCESS ON *.* TO 'arthur'@'localhost';
```

Et voilà le service se met en route et les sauvegardes toutes les 10 minutes !

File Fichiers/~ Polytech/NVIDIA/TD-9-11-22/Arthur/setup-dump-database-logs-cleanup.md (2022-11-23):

### Clean les logs 

On veut que notre fichier ne fasse pas plus que 10 Ko. Nos logs sont stockés dans ici : 

```shell 
LOG="/var/log/dump-mysql.log" 
```
Pour contrôler la taille du fichier on utilise ``du`` (disk usage) avec ``-B K`` pour avoir un résultat en Ko : 
```shell
VOLUME=$(du -B K $LOG)
```

Enfin au moment de quitter, si le fichier est plein on remplace la dernière ligne : 
```shell
echo "Fin des logs, fichier log plein - $DATE" > $LOG
```
Sinon on écrit à la suite la fin du fichier log : 
```shell
echo "Fin des logs - $DATE" >> $LOG
```

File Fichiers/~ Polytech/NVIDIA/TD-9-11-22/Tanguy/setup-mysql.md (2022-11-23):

# Comment installer mysql:

```shell

sudo apt update

sudo apt install mysql-server

sudo systemctl start mysql.service

sudo mysql

mysql>SELECT user,authentication_string,plugin,host FROM mysql.user;

mysql>ALTER USER 'root'@'localhost' IDENTIFIED WITH mysql_native_password BY 'TaNg2001@#!';
```

Pour le premier mot de passe j'ai eu une erreur: MySQL ERROR 1819 (HY000): Your password does not satisfy the current policy requirements

```shell
mysql> SHOW VARIABLES LIKE 'validate_password%';

mysql>exit

sudo mysql_secure_installation
```

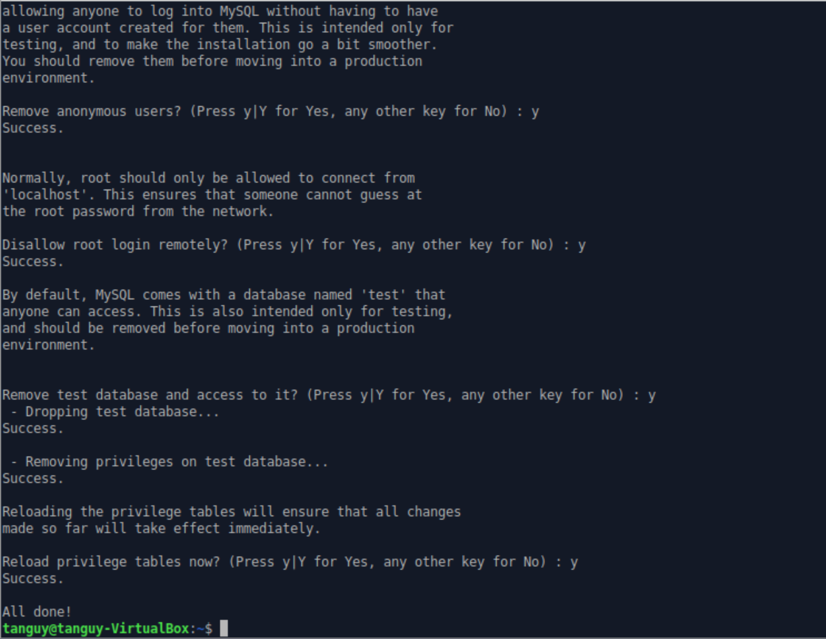
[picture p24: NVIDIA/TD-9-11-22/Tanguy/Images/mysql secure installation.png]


```shell

sudo mysql

mysql> CREATE USER 'tanguy'@'localhost' IDENTIFIED BY 'TaNg2001@#!';

mysql>GRANT SHOW DATABASES, SELECT, LOCK TABLES ON *.* TO 'tanguy'@'localhost';

mysql> FLUSH PRIVILEGES;

mysql> show databases;

mysql> exit

sudo systemctl status mysql.service

```

# Comment importer la base de données:

```shell

mkdir TdBDD

cd TdBDD

wget https://www.mysqltutorial.org/wp-content/uploads/2018/03/mysqlsampledatabase.zip

unzip mysqlsampledatabase.zip

sudo apt install bzip2

bzip2 mysqlsampledatabase.sql

unzip mysqlsampledatabase.zip

mysql -u tanguy -p < /home/TdBDD/mysqlsampledatabase.sql

mysql -u tanguy -p

Enter password:

```

```shell
mysql>show databases;
```

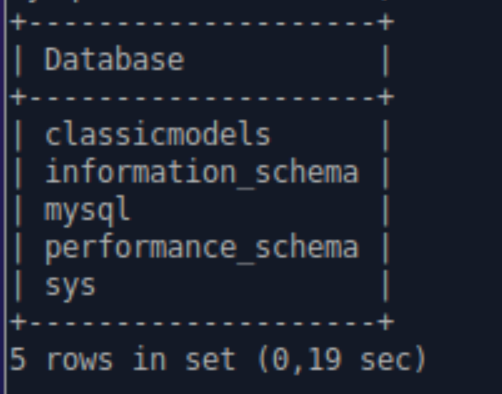
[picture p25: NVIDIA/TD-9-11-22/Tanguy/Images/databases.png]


```shell
mysql>use classicmodels;

mysql>show tables;

mysql> exit
```

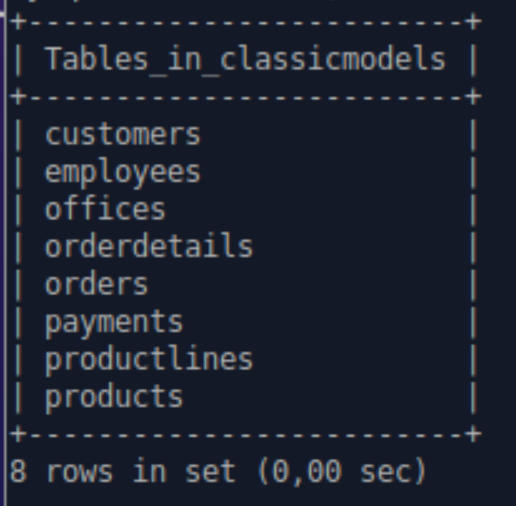
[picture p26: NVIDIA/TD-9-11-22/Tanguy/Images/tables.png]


# Créer le script:

```shell
vim dump-database.sh
```

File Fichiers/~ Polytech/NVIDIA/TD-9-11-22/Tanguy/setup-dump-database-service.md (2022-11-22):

# Comment configurer le service:

D'après: https://azurplus.fr/comment-executer-un-programme-linux-au-demarrage-avec-systemd/

```shell
sudo chmod +x dump-database.sh

./dump-database.sh

sudo nano /lib/systemd/system/dump-database.service

sudo systemctl daemon-reload

sudo systemctl enable dump-database.service

sudo systemctl start dump-database.service

sudo systemctl status dump-database.service

```

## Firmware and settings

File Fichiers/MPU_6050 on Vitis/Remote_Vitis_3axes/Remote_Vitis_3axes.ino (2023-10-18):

#define dir_g 32
#define pwm_g 2
#define dir_d 33
#define pwm_d 3
#define dir_b 12
#define pwm_b 5


int speed = 0;
int roll = 0.0;
int pitch = 0.0;
char direction = 'S';

void setup() {
  pinMode(dir_g, OUTPUT);
  pinMode(pwm_g, OUTPUT);
  pinMode(dir_d, OUTPUT);
  pinMode(pwm_d, OUTPUT);
  pinMode(dir_b, OUTPUT);
  pinMode(pwm_b, OUTPUT);

  // Configuration de la liaison Bluetooth
  Serial1.begin(9600);
  Serial.begin(9600);

  // Initialise les pins à l'état bas
  digitalWrite(dir_g, LOW);
  analogWrite(pwm_g, 0);
  digitalWrite(dir_d, LOW);
  analogWrite(pwm_d, 0);
  digitalWrite(dir_b, LOW);
  analogWrite(pwm_b, 0);
}

void loop() {


  if (Serial1.available()) {
    char c = Serial1.read();
    //Serial.print(c);

  
    

      if (c == 'V') {
      speed = Serial1.parseInt();
      Serial.print("new speed : "); 
      Serial.print(speed); 
      analogWrite(pwm_g, speed);
      analogWrite(pwm_d, speed);
      }

    else if (c == 'P') {
      pitch = Serial1.parseInt();
      Serial.print("new pitch : ");
      Serial.println(pitch);

    }

    else if (c == 'W') {
      roll = Serial1.parseInt();
      Serial.print("new roll : ");
      Serial.println(roll);

    }

    float absRoll = abs(roll);
  float absPitch = abs(pitch);

  if (absRoll > absPitch) {
    if (roll > 0) {
      direction = 'R'; // Droite
    } else if (roll < 0) {
      direction = 'L'; // Gauche
    }
  } else {
    if (pitch > 0) {
      direction = 'U'; // Avancer
    } else if (pitch < 0) {
      direction = 'D'; // Reculer
    }
  }


if (direction == 'D') {
      digitalWrite(dir_g, HIGH);
      digitalWrite(dir_d, HIGH);
      analogWrite(pwm_g, speed);
      analogWrite(pwm_d, speed);

    } else if (direction  == 'U') {
      digitalWrite(dir_g, LOW);
      digitalWrite(dir_d, LOW);
      analogWrite(pwm_g, speed);
      analogWrite(pwm_d, speed);

    } else if (direction  == 'R') {
      digitalWrite(dir_g, LOW);
      digitalWrite(dir_d, HIGH);
      analogWrite(pwm_g, speed);
      analogWrite(pwm_d, speed);

    } else if (direction  == 'L') {
      digitalWrite(dir_g, HIGH);
      digitalWrite(dir_d, LOW);
      analogWrite(pwm_g, speed);
      analogWrite(pwm_d, speed);
    }
    

    else if (c == 'B') {
      digitalWrite(dir_b, LOW);
      analogWrite(pwm_b, 255);
      Serial.println("bas");
    } else if (c == 'H') {
      digitalWrite(dir_b, HIGH);
      analogWrite(pwm_b, 255);
      Serial.println("haut");
    

    
    
    }
    }
  }
  

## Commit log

2022-10-18 Create Tanguy - Rapport de séance n°1.pdf
2022-10-22 Create Rapport de Séance n°2.pdf
2022-10-29 Create Rapport de séance n°3.pdf
2022-11-14 Devoirs Boîte CAO Tanguy
    [Boite Finale v3.f3d]
2022-11-14 Devoir CAO Tanguy Vitre
    [vitre.dxf]
2022-11-19 Rapport de Séance 4 Tanguy
2022-11-26 rapport de séance 5
2022-11-26 Create Arthur - Rapport de séance n°5.pdf
2022-12-17 New file organisation
    [Boite Finale v3.f3d, Boîte Arduino Mega Export .f3d, vitre.dxf]
2023-01-21 Code arduino
2023-02-04 Create Rapport de séance n°11.pdf
2023-02-18 upload rapport de seance 13
2023-03-06 upload rapport de seance 14
2023-03-10 upload rapport de seance 15
2023-05-16 File Vitis
    [Boite Finale v3.f3d, Boîte Arduino Mega Export .f3d, vitre.dxf]
